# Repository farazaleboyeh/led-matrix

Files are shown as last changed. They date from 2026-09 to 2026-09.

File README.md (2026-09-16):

# Custom-Built Music Display

## Goal
The purpose of this project has been to extend my skills as a hardware engineer, specifically in regards to the development of embedded systems. Thus, I challenged myself to build a complete system from scratch that encompasses the entire development lifecycle. From schematic design and PCB layout in KiCad, to writing efficient C++ firmware for Wi-Fi networking, memory management, & custom LED multiplexing.

## Overview
Repository includes the firmwmare used to show the artwork of a currently streaming song from Spotify onto a custom-built 10x10 display, as well as all primary KiCad project files used to design the system itself. Some examples images of the display in its most recent state are available below.

<div align="center">
  <table>
    <tr>
      <td align="center">
        <a href="assets/demo1.jpeg">
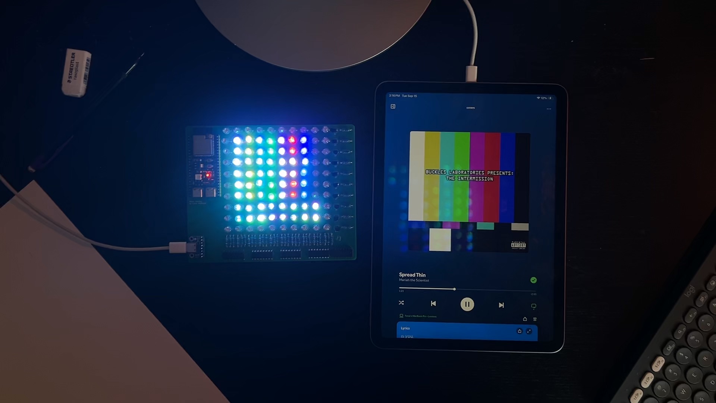
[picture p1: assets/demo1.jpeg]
Example Image 1
          
        </a>
        <br />
        <sub><em>Example 1, raw LEDs exposed.</em></sub>
      </td>
      <td align="center">
        <a href="assets/demo5.jpeg">
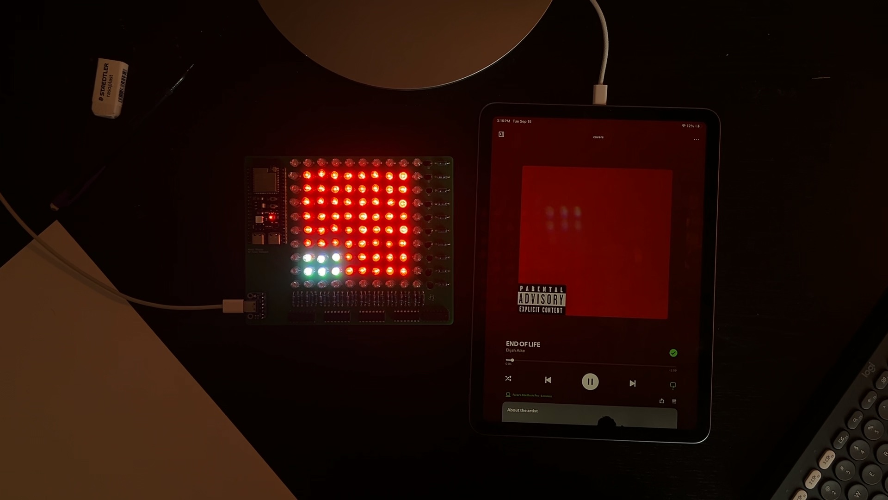
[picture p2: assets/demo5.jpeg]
Example Image 2
          
        </a>
        <br />
        <sub><em>Example 2, raw LEDs exposed.</em></sub>
      </td>
    </tr>
    <tr>
      <td align="center">
        <a href="assets/demo4.jpeg">
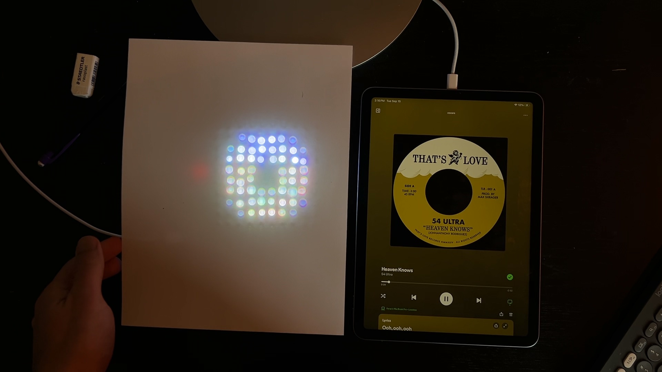
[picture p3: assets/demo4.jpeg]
Example Image 3
          
        </a>
        <br />
        <sub><em>Example 3, makeshift diffuser overlayed. </em></sub>
      </td>
      <td align="center">
      <a href="assets/demo2.jpeg">
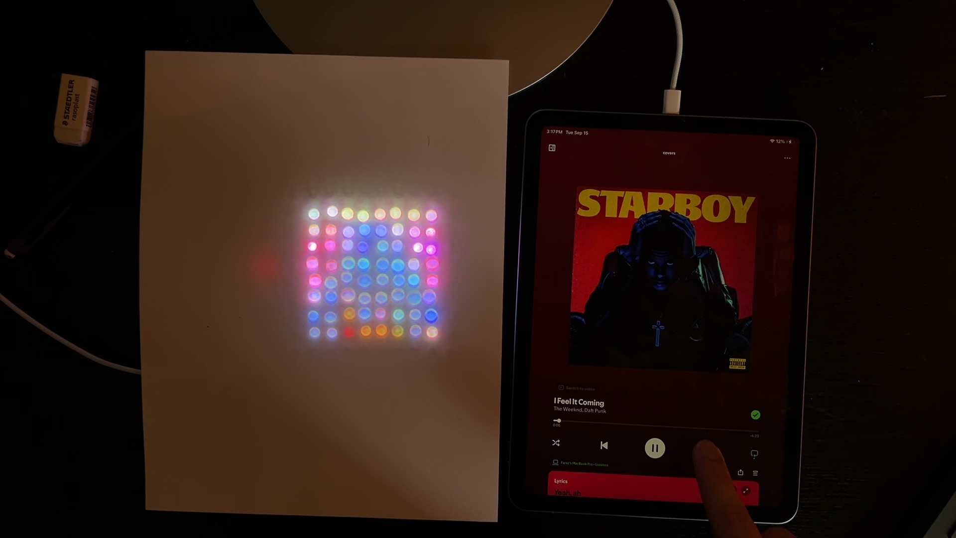
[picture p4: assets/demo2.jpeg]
Example Image 4
          
        </a>
        <br />
        <sub><em>Example 4, makeshift diffuser overlayed.</em></sub>
      </td>
    </tr>
  </table>
</div>

The system works by first calling Spotify's APIs to fetch all data regarding the user's playing music. From the given information, a link to the  album art is then used to store all JPEG data (as a stream of bytes) to an internal buffer. The TJpg Decoder library is used to decode the buffer as RGB565 data (locally), which perpetually reaches out to a separate callback function, which converts again to RGB888 and also writes to the display's back framebuffer. When the front and back framebuffers are swapped, a continuously firing interrupt displays the artwork by streaming the bitplanes (sequentially by time slice and physical row), to the display's shift registers. 

## Hardware 
### Comprehensive Component List
* 100 RGB LEDs, multiplexed
* 10 100Ω, 10 150Ω, 10 220Ω, & 10 1kΩ resistors
* 5 (74HC595) shift registers, daisy-chained.
* 10 PNP BJTs
* An ESP32-S3, development board
* A USB-C breakout board

### Core Physical Functionality
The display is driven by an ESP32 microcontroller, which is responsible for streaming color data to the chained shift registers, among other tasks. Transistors are present along all rows which act as high-side power switches between the main power rail and the shared anodes, so that the (output-limited) shift registers are not solely responsible for driving entire rows themselves. 1kΩ current-limiting resistors are present along rows to protect the shift registers and LEDs from overheating & overcurrent, with per-color resistors along each column to finely tune color output (100Ω for red columns, 150Ω, green, & 220Ω blue). Images of the schematic, PCB design, & soldered board are all shown below for reference.

<div align="center">
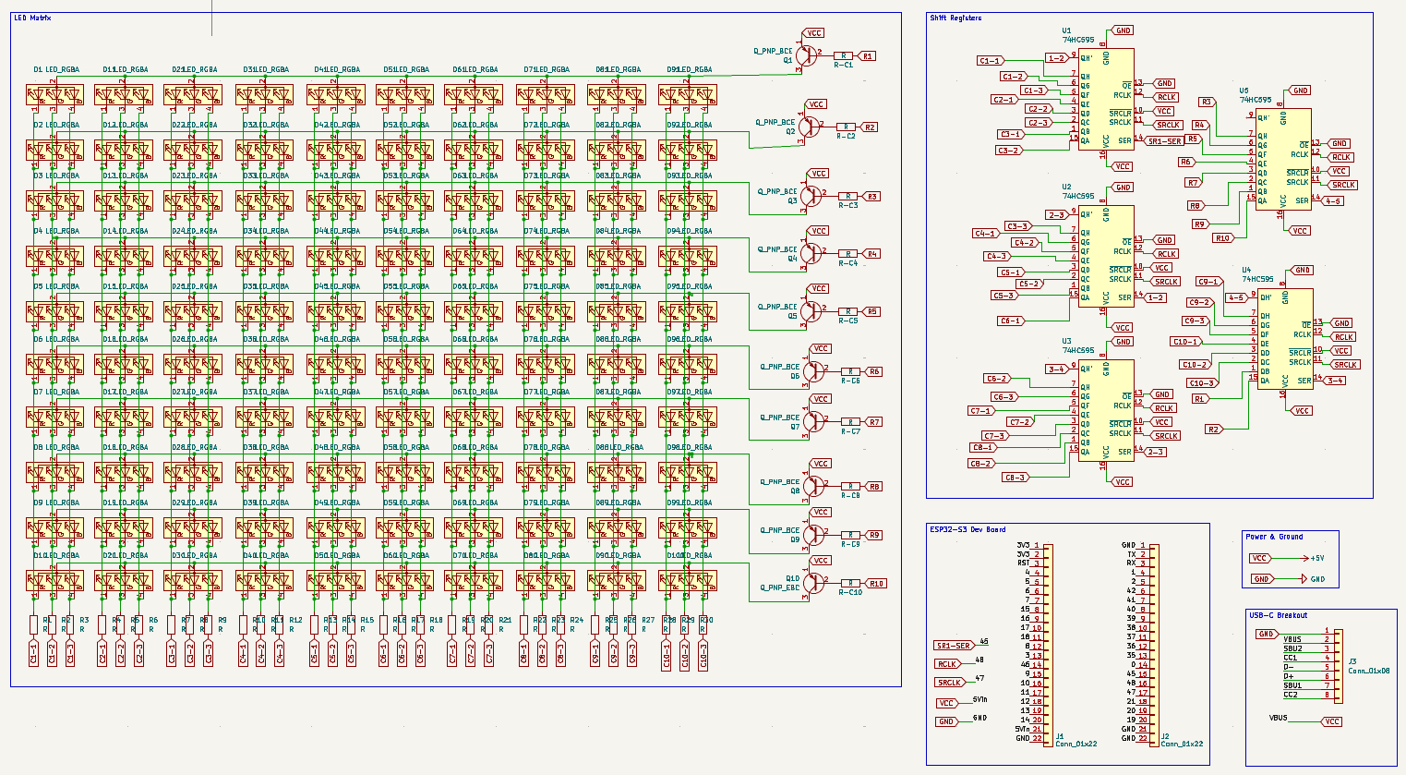
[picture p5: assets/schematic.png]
Image of KiCad Schematic
  
  <br />
  <sub><i>Schematic diagram, designed in KiCad.</i></sub>
</div>

<br />

<div align="center">
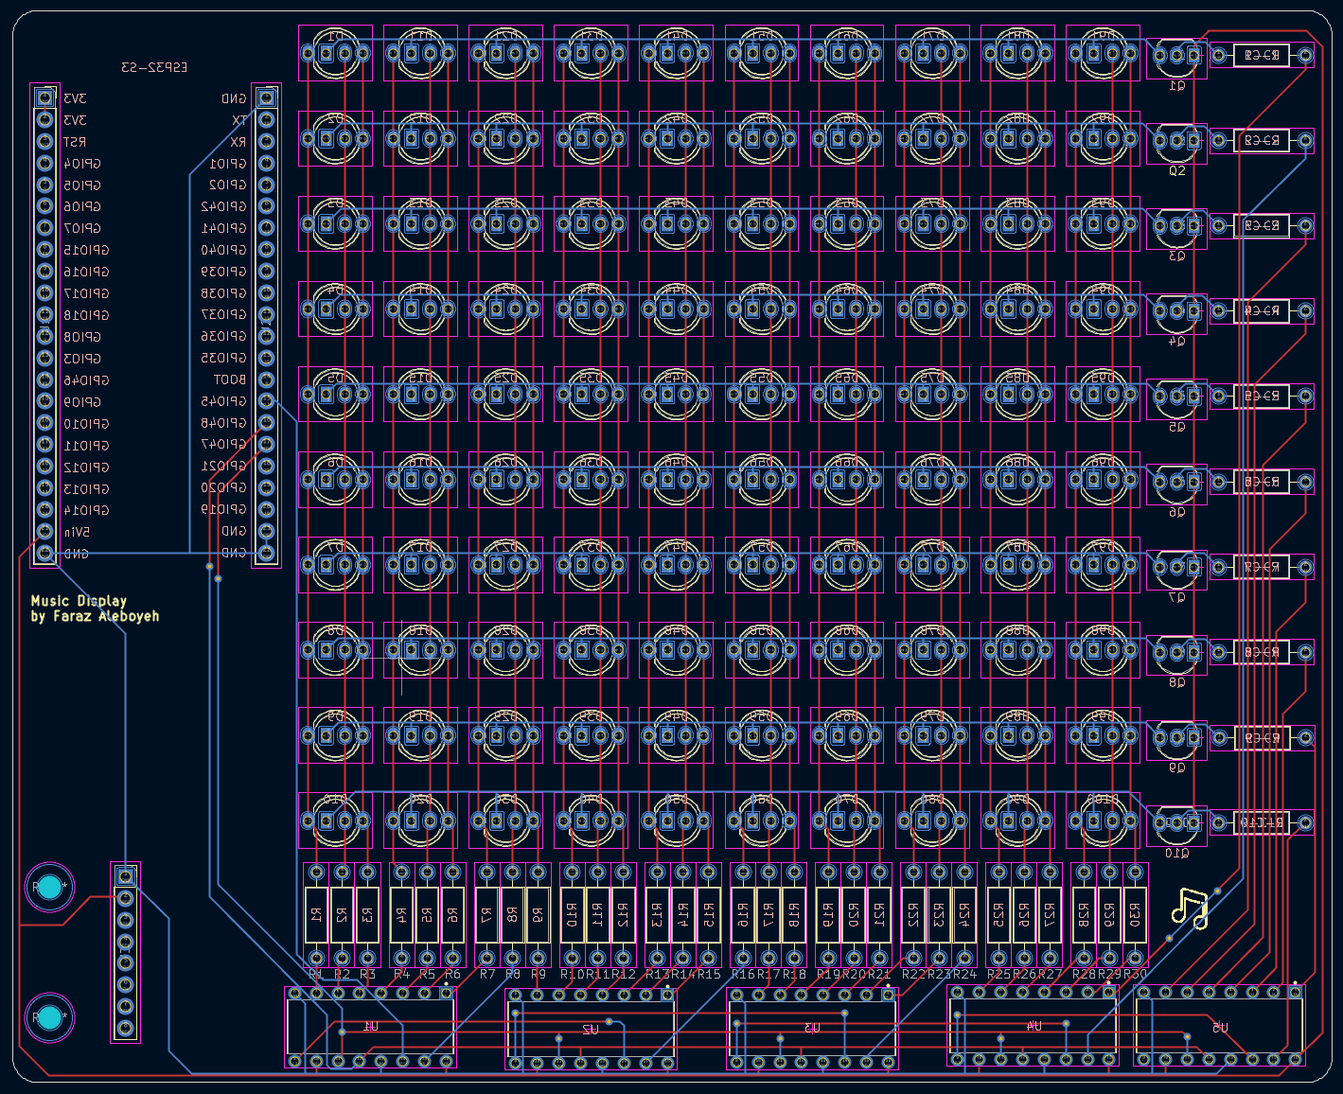
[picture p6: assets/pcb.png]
Image of KiCad PCB Layout
  
  <br />
  <sub><i>PCB layout, designed in KiCad.</i></sub>
</div>

<br />

<div align="center">
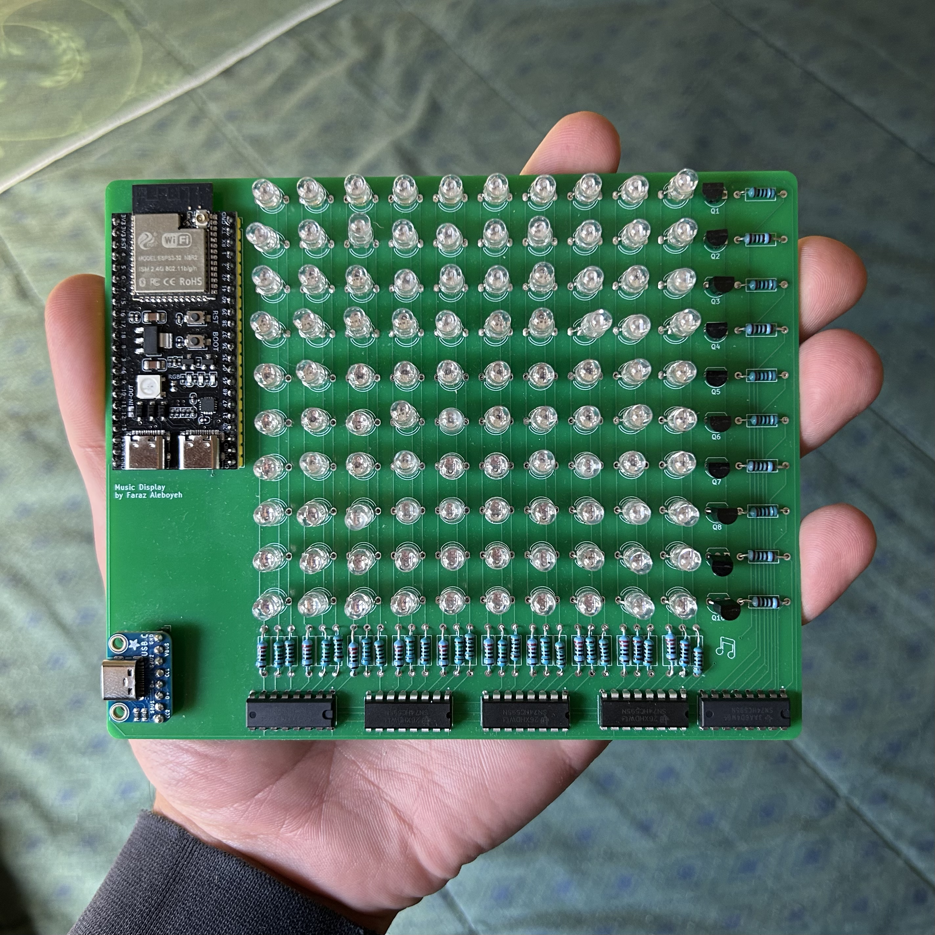
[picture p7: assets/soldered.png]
Image of Soldered PCB
  
  <br />
  <sub><i>Soldered PCB, note that the breakout is still missing the screws and washers necessary for securing it to the board but is otherwise complete.</i></sub>
</div>

## Firmware 
### Core Logical Functionality

<div align="center">
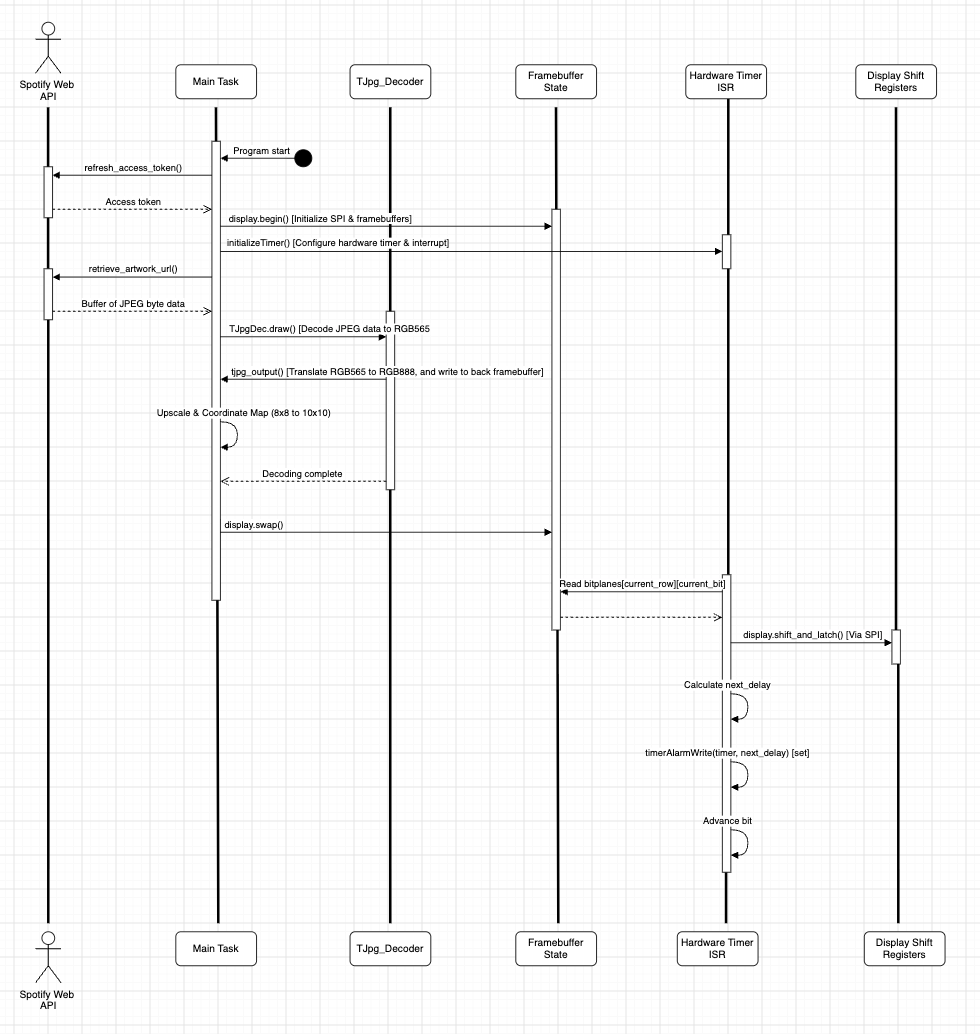
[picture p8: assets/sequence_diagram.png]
Image of UML Sequence Diagram
  
  <br />
  <sub><i>UML sequence diagram, complete program flow.</i></sub>
</div>

### API Access
The basis of the project lies in interfacing with Spotify's APIs to receieve user data regarding their currently playing music. Every time the program begins running, and after a successful Wi-Fi connection is established, one of the first tasks to run is the retrieval of a new Access Token from Spotify's servers. As per the Spotify's requirements, Access Tokens are inherently ephemeral, expiring automatically every 3600 seconds (1 hour) regardless of scope. Thus, a function runs every 55 minutes to renew the Activation Token automatically, ensuring the display can be used for extended periods of time. 

There is not currently, however, any avenue for renewing the Refresh Tokens  automatically at the time of writing. Given they expire every 4 months, an implementation for such was not listed as high-enough priority but is in the works. 

### Interrupt-Driven Binary Code Modulation (BCM)
Instead of standard PWM, which would demand an unsustainable 2,550 SPI updates per frame (10 rows x 255 steps) and cause severe CPU starvation, the driver implements Binary Code Modulation via the microcontroller's hardware timer. By shifting only 8 exponentially weighted bitplanes per row (5µs, 10µs, 20µs, etc.), BCM slashes bus traffic by 97% to just 80 updates per frame, reconstructing full 8-bit color depth through visual persistence while leaving the CPU free for WiFi and JPEG decoding.

### Double Buffering
To prevent screen tearing during WiFi fetches or JPEG decoding: Operations draw to a back framebuffer (`draw_buffer`), `display.swap()` unpacks the back buffer into physical bitplanes (`bitplanes[10][8][5]`), & the ISR (`on_timer`) exclusively reads from the active bitplanes.

## Progress
A list of the main tasks in progress for this project:
* Upscaling the 8x8 artwork to 10x10
* Implementing animated song transitions
* Designing and 3D printing an enlosure and diffuser

A non-exhaustive list of ideas for future iterations of this project:
* LEDs & all other display hardware sitting on separate PCBs
* Playback controls (buttons, or other sensors for touchless playback)
* Transition firmware from Arduino framework to ESP-IDF with FreeRTOS

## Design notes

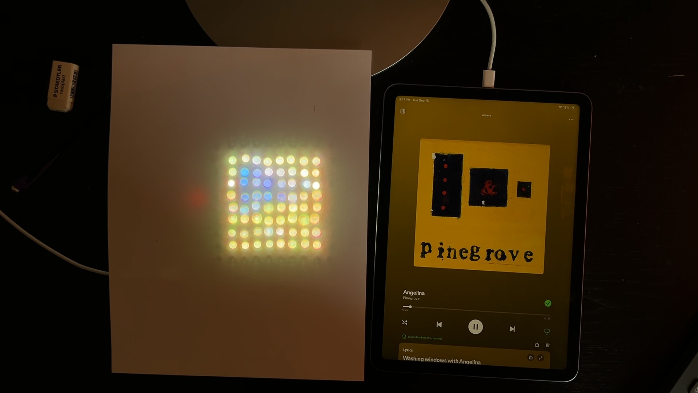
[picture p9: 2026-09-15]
assets/demo3.jpeg

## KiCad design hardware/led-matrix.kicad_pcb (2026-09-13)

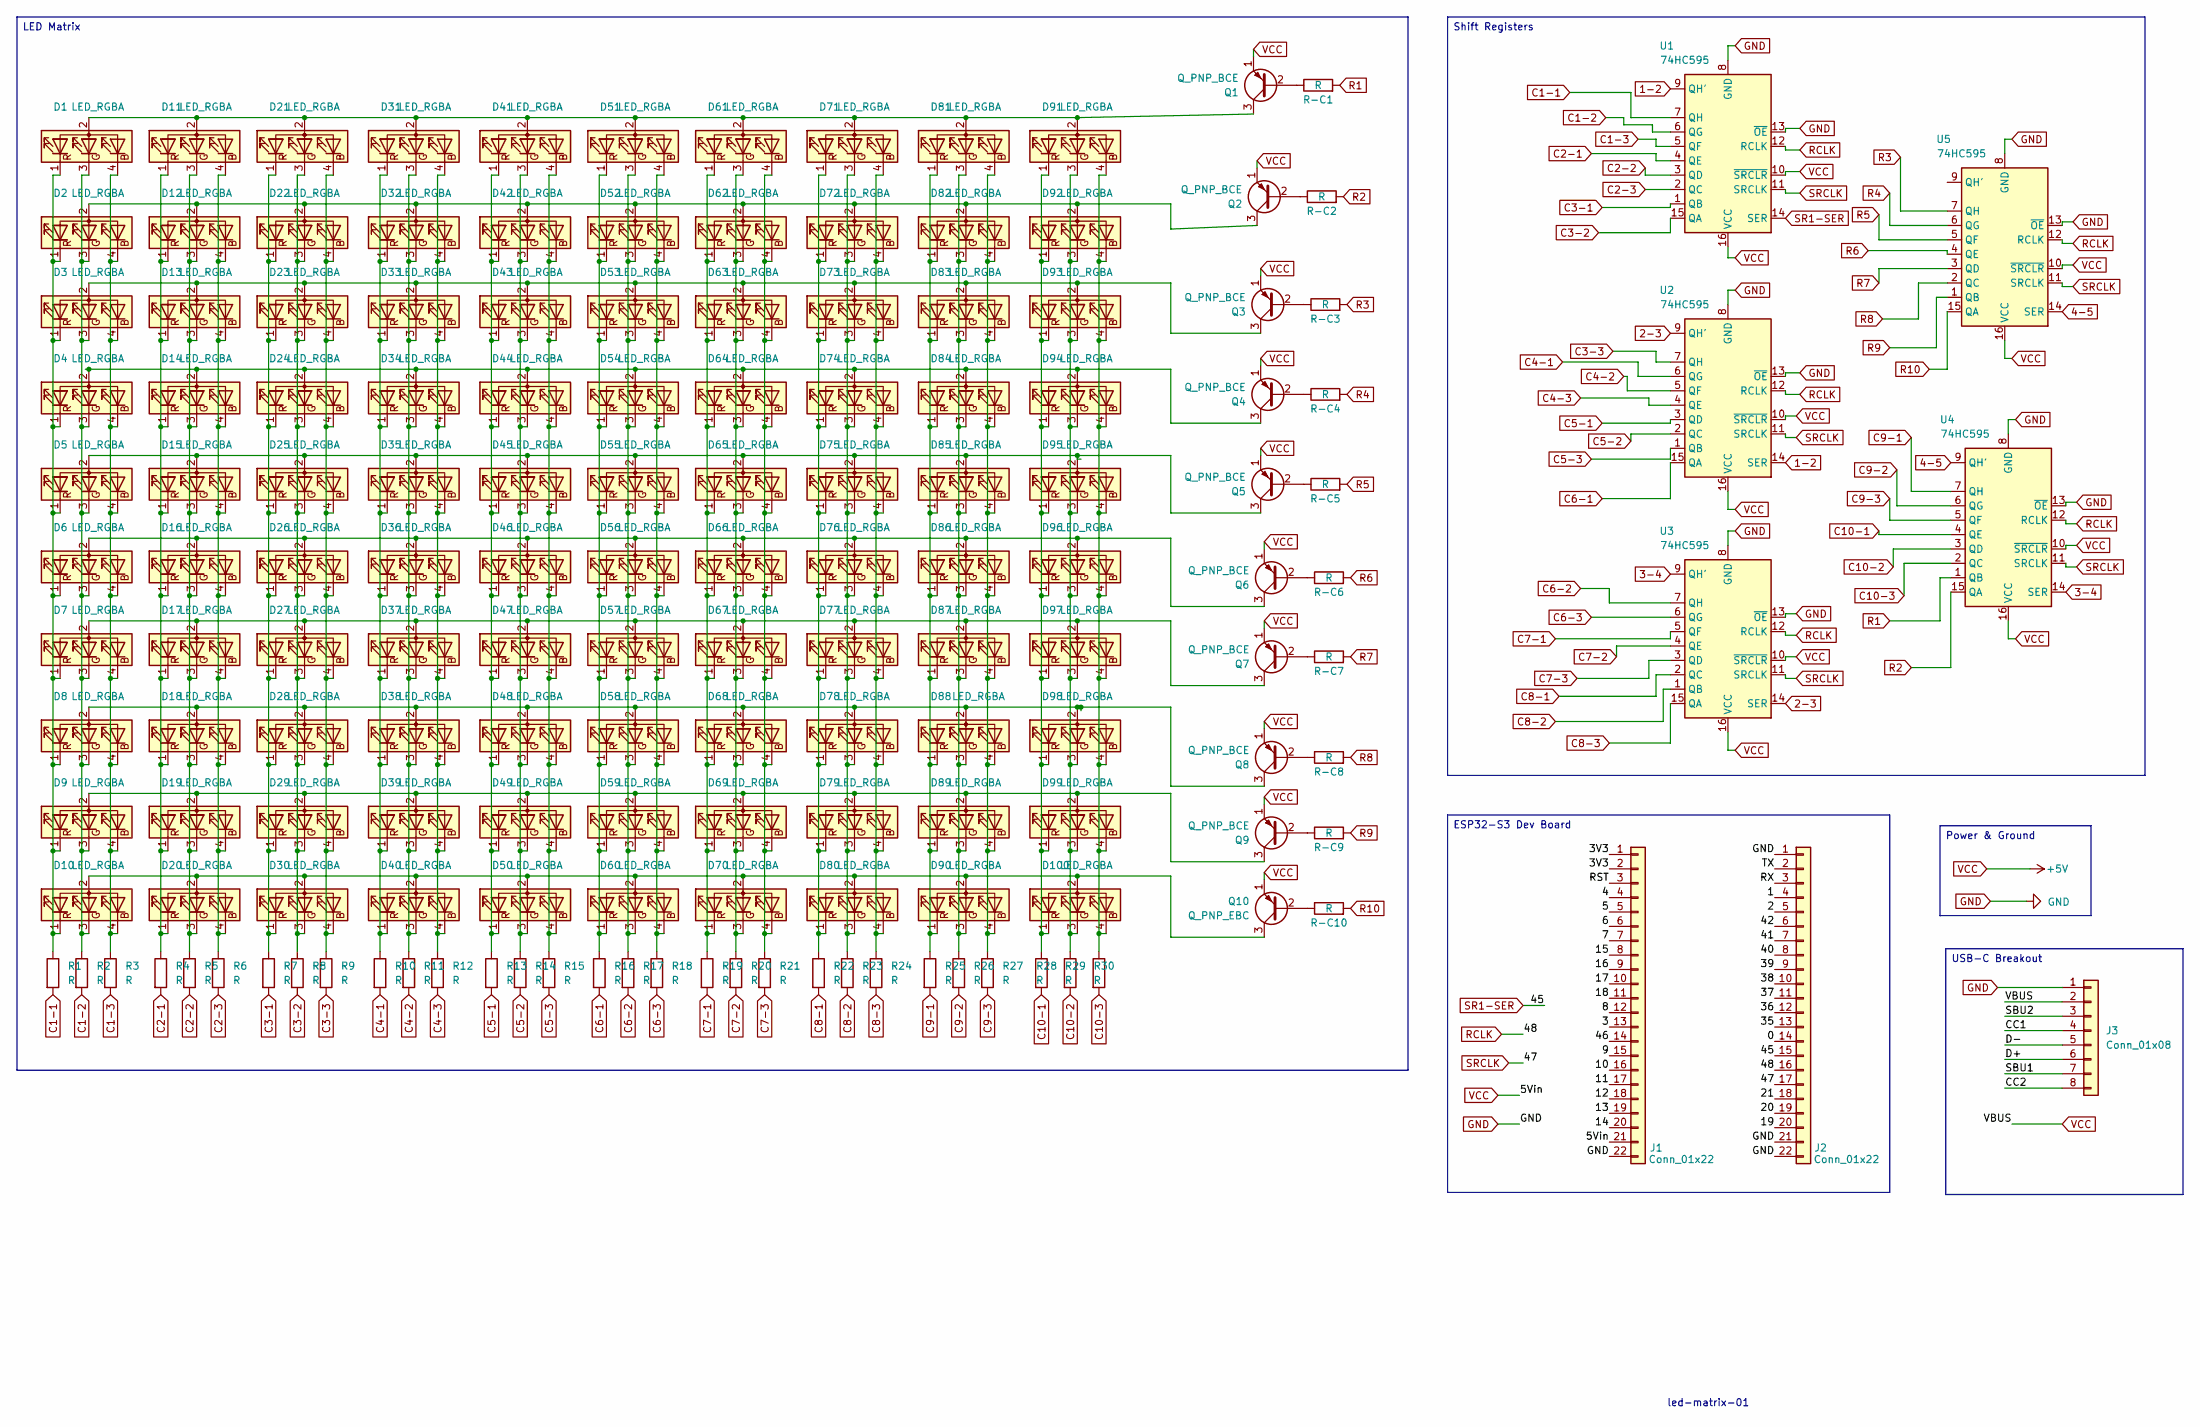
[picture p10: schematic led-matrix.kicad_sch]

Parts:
D1, D2, D3, D4, D5, D6, D7, D8, D9, D10, D11, D12, D13, D14, D15, D16, D17, D18, D19, D20, D21, D22, D23, D24, D25, D26, D27, D28, D29, D30, D31, D32, D33, D34, D35, D36, D37, D38, D39, D40, D41, D42, D43, D44, D45, D46, D47, D48, D49, D50, D51, D52, D53, D54, D55, D56, D57, D58, D59, D60, D61, D62, D63, D64, D65, D66, D67, D68, D69, D70, D71, D72, D73, D74, D75, D76, D77, D78, D79, D80, D81, D82, D83, D84, D85, D86, D87, D88, D89, D90, D91, D92, D93, D94, D95, D96, D97, D98, D99, D100: LED_RGBA; LED_D5.0mm-4_RGB_Wide_Pins
J1, J2: Conn_01x22; PinSocket_1x22_P2.54mm_Vertical
J3: Conn_01x08; PinSocket_1x08_P2.54mm_Vertical
Q1, Q2, Q3, Q4, Q5, Q6, Q7, Q8, Q9: Q_PNP_BCE; TO-92_Inline_Wide
Q10: Q_PNP_EBC; TO-92_Inline_Wide
R1, R2, R3, R4, R5, R6, R7, R8, R9, R10, R11, R12, R13, R14, R15, R16, R17, R18, R19, R20, R21, R22, R23, R24, R25, R26, R27, R28, R29, R30: R; R_Axial_DIN0207_L6.3mm_D2.5mm_P10.16mm_Horizontal
R-C1, R-C2, R-C3, R-C4, R-C5, R-C6, R-C7, R-C8, R-C9, R-C10: R; R_Axial_DIN0207_L6.3mm_D2.5mm_P10.16mm_Horizontal
U1, U2, U3, U4, U5: 74HC595; DIP794W45P254L1969H508Q16

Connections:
1-2: U1.9 (QH'), U2.14 (SER)
2-3: U2.9 (QH'), U3.14 (SER)
3-4: U3.9 (QH'), U4.14 (SER)
4-5: U4.9 (QH'), U5.14 (SER)
/0: J2.14
/1: J2.4
/2: J2.5
/3: J1.13
/3V3: J1.1, J1.2
/4: J1.4
/5: J1.5
/6: J1.6
/7: J1.7
/8: J1.12
/9: J1.15
/10: J1.16
/11: J1.17
/12: J1.18
/13: J1.19
/14: J1.20
/15: J1.8
/16: J1.9
/17: J1.10
/18: J1.11
/19: J2.20
/20: J2.19
/21: J2.18
/35: J2.13
/36: J2.12
/37: J2.11
/38: J2.10
/39: J2.9
/40: J2.8
/41: J2.7
/42: J2.6
/46: J1.14
/CC1: J3.4
/CC2: J3.8
/D+: J3.6
/D-: J3.5
/RST: J1.3
/RX: J2.3
/SBU1: J3.7
/SBU2: J3.3
/TX: J2.2
C1-1: R1.2, U1.7 (QH)
C1-2: R2.2, U1.6 (QG)
C1-3: R3.2, U1.5 (QF)
C2-1: R4.2, U1.4 (QE)
C2-2: R5.2, U1.3 (QD)
C2-3: R6.2, U1.2 (QC)
C3-1: R7.2, U1.1 (QB)
C3-2: R8.2, U1.15 (QA)
C3-3: R9.2, U2.7 (QH)
C4-1: R10.2, U2.6 (QG)
C4-2: R11.2, U2.5 (QF)
C4-3: R12.2, U2.4 (QE)
C5-1: R13.2, U2.3 (QD)
C5-2: R14.2, U2.2 (QC)
C5-3: R15.2, U2.1 (QB)
C6-1: R16.2, U2.15 (QA)
C6-2: R17.2, U3.7 (QH)
C6-3: R18.2, U3.6 (QG)
C7-1: R19.2, U3.5 (QF)
C7-2: R20.2, U3.4 (QE)
C7-3: R21.2, U3.3 (QD)
C8-1: R22.2, U3.2 (QC)
C8-2: R23.2, U3.1 (QB)
C8-3: R24.2, U3.15 (QA)
C9-1: R25.2, U4.7 (QH)
C9-2: R26.2, U4.6 (QG)
C9-3: R27.2, U4.5 (QF)
C10-1: R28.2, U4.4 (QE)
C10-2: R29.2, U4.3 (QD)
C10-3: R30.2, U4.2 (QC)
GND: J1.22, J2.1, J2.21, J2.22, J3.1, U1.8 (GND), U1.13 (~OE), U2.8 (GND), U2.13 (~OE), U3.8 (GND), U3.13 (~OE), U4.8 (GND), U4.13 (~OE), U5.8 (GND), U5.13 (~OE)
unnamed: D1.2 (A), D11.2 (A), D21.2 (A), D31.2 (A), D41.2 (A), D51.2 (A), D61.2 (A), D71.2 (A), D81.2 (A), D91.2 (A), Q1.3 (C)
unnamed: D1.4 (BK), D2.4 (BK), D3.4 (BK), D4.4 (BK), D5.4 (BK), D6.4 (BK), D7.4 (BK), D8.4 (BK), D9.4 (BK), D10.4 (BK), R3.1
unnamed: D1.3 (GK), D2.3 (GK), D3.3 (GK), D4.3 (GK), D5.3 (GK), D6.3 (GK), D7.3 (GK), D8.3 (GK), D9.3 (GK), D10.3 (GK), R2.1
unnamed: D1.1 (RK), D2.1 (RK), D3.1 (RK), D4.1 (RK), D5.1 (RK), D6.1 (RK), D7.1 (RK), D8.1 (RK), D9.1 (RK), D10.1 (RK), R1.1
unnamed: D10.2 (A), D20.2 (A), D30.2 (A), D40.2 (A), D50.2 (A), D60.2 (A), D70.2 (A), D80.2 (A), D90.2 (A), D100.2 (A), Q10.3 (C)
unnamed: D11.4 (BK), D12.4 (BK), D13.4 (BK), D14.4 (BK), D15.4 (BK), D16.4 (BK), D17.4 (BK), D18.4 (BK), D19.4 (BK), D20.4 (BK), R6.1
unnamed: D11.3 (GK), D12.3 (GK), D13.3 (GK), D14.3 (GK), D15.3 (GK), D16.3 (GK), D17.3 (GK), D18.3 (GK), D19.3 (GK), D20.3 (GK), R5.1
unnamed: D11.1 (RK), D12.1 (RK), D13.1 (RK), D14.1 (RK), D15.1 (RK), D16.1 (RK), D17.1 (RK), D18.1 (RK), D19.1 (RK), D20.1 (RK), R4.1
unnamed: D2.2 (A), D12.2 (A), D22.2 (A), D32.2 (A), D42.2 (A), D52.2 (A), D62.2 (A), D72.2 (A), D82.2 (A), D92.2 (A), Q2.3 (C)
unnamed: D3.2 (A), D13.2 (A), D23.2 (A), D33.2 (A), D43.2 (A), D53.2 (A), D63.2 (A), D73.2 (A), D83.2 (A), D93.2 (A), Q3.3 (C)
unnamed: D4.2 (A), D14.2 (A), D24.2 (A), D34.2 (A), D44.2 (A), D54.2 (A), D64.2 (A), D74.2 (A), D84.2 (A), D94.2 (A), Q4.3 (C)
unnamed: D5.2 (A), D15.2 (A), D25.2 (A), D35.2 (A), D45.2 (A), D55.2 (A), D65.2 (A), D75.2 (A), D85.2 (A), D95.2 (A), Q5.3 (C)
unnamed: D6.2 (A), D16.2 (A), D26.2 (A), D36.2 (A), D46.2 (A), D56.2 (A), D66.2 (A), D76.2 (A), D86.2 (A), D96.2 (A), Q6.3 (C)
unnamed: D7.2 (A), D17.2 (A), D27.2 (A), D37.2 (A), D47.2 (A), D57.2 (A), D67.2 (A), D77.2 (A), D87.2 (A), D97.2 (A), Q7.3 (C)
unnamed: D8.2 (A), D18.2 (A), D28.2 (A), D38.2 (A), D48.2 (A), D58.2 (A), D68.2 (A), D78.2 (A), D88.2 (A), D98.2 (A), Q8.3 (C)
unnamed: D9.2 (A), D19.2 (A), D29.2 (A), D39.2 (A), D49.2 (A), D59.2 (A), D69.2 (A), D79.2 (A), D89.2 (A), D99.2 (A), Q9.3 (C)
unnamed: D21.4 (BK), D22.4 (BK), D23.4 (BK), D24.4 (BK), D25.4 (BK), D26.4 (BK), D27.4 (BK), D28.4 (BK), D29.4 (BK), D30.4 (BK), R9.1
unnamed: D21.3 (GK), D22.3 (GK), D23.3 (GK), D24.3 (GK), D25.3 (GK), D26.3 (GK), D27.3 (GK), D28.3 (GK), D29.3 (GK), D30.3 (GK), R8.1
unnamed: D21.1 (RK), D22.1 (RK), D23.1 (RK), D24.1 (RK), D25.1 (RK), D26.1 (RK), D27.1 (RK), D28.1 (RK), D29.1 (RK), D30.1 (RK), R7.1
unnamed: D31.4 (BK), D32.4 (BK), D33.4 (BK), D34.4 (BK), D35.4 (BK), D36.4 (BK), D37.4 (BK), D38.4 (BK), D39.4 (BK), D40.4 (BK), R12.1
unnamed: D31.3 (GK), D32.3 (GK), D33.3 (GK), D34.3 (GK), D35.3 (GK), D36.3 (GK), D37.3 (GK), D38.3 (GK), D39.3 (GK), D40.3 (GK), R11.1
unnamed: D31.1 (RK), D32.1 (RK), D33.1 (RK), D34.1 (RK), D35.1 (RK), D36.1 (RK), D37.1 (RK), D38.1 (RK), D39.1 (RK), D40.1 (RK), R10.1
unnamed: D41.4 (BK), D42.4 (BK), D43.4 (BK), D44.4 (BK), D45.4 (BK), D46.4 (BK), D47.4 (BK), D48.4 (BK), D49.4 (BK), D50.4 (BK), R15.1
unnamed: D41.3 (GK), D42.3 (GK), D43.3 (GK), D44.3 (GK), D45.3 (GK), D46.3 (GK), D47.3 (GK), D48.3 (GK), D49.3 (GK), D50.3 (GK), R14.1
unnamed: D41.1 (RK), D42.1 (RK), D43.1 (RK), D44.1 (RK), D45.1 (RK), D46.1 (RK), D47.1 (RK), D48.1 (RK), D49.1 (RK), D50.1 (RK), R13.1
unnamed: D51.4 (BK), D52.4 (BK), D53.4 (BK), D54.4 (BK), D55.4 (BK), D56.4 (BK), D57.4 (BK), D58.4 (BK), D59.4 (BK), D60.4 (BK), R18.1
unnamed: D51.3 (GK), D52.3 (GK), D53.3 (GK), D54.3 (GK), D55.3 (GK), D56.3 (GK), D57.3 (GK), D58.3 (GK), D59.3 (GK), D60.3 (GK), R17.1
unnamed: D51.1 (RK), D52.1 (RK), D53.1 (RK), D54.1 (RK), D55.1 (RK), D56.1 (RK), D57.1 (RK), D58.1 (RK), D59.1 (RK), D60.1 (RK), R16.1
unnamed: D61.4 (BK), D62.4 (BK), D63.4 (BK), D64.4 (BK), D65.4 (BK), D66.4 (BK), D67.4 (BK), D68.4 (BK), D69.4 (BK), D70.4 (BK), R21.1
unnamed: D61.3 (GK), D62.3 (GK), D63.3 (GK), D64.3 (GK), D65.3 (GK), D66.3 (GK), D67.3 (GK), D68.3 (GK), D69.3 (GK), D70.3 (GK), R20.1
unnamed: D61.1 (RK), D62.1 (RK), D63.1 (RK), D64.1 (RK), D65.1 (RK), D66.1 (RK), D67.1 (RK), D68.1 (RK), D69.1 (RK), D70.1 (RK), R19.1
unnamed: D71.4 (BK), D72.4 (BK), D73.4 (BK), D74.4 (BK), D75.4 (BK), D76.4 (BK), D77.4 (BK), D78.4 (BK), D79.4 (BK), D80.4 (BK), R24.1
unnamed: D71.3 (GK), D72.3 (GK), D73.3 (GK), D74.3 (GK), D75.3 (GK), D76.3 (GK), D77.3 (GK), D78.3 (GK), D79.3 (GK), D80.3 (GK), R23.1
unnamed: D71.1 (RK), D72.1 (RK), D73.1 (RK), D74.1 (RK), D75.1 (RK), D76.1 (RK), D77.1 (RK), D78.1 (RK), D79.1 (RK), D80.1 (RK), R22.1
unnamed: D81.4 (BK), D82.4 (BK), D83.4 (BK), D84.4 (BK), D85.4 (BK), D86.4 (BK), D87.4 (BK), D88.4 (BK), D89.4 (BK), D90.4 (BK), R27.1
unnamed: D81.3 (GK), D82.3 (GK), D83.3 (GK), D84.3 (GK), D85.3 (GK), D86.3 (GK), D87.3 (GK), D88.3 (GK), D89.3 (GK), D90.3 (GK), R26.1
unnamed: D81.1 (RK), D82.1 (RK), D83.1 (RK), D84.1 (RK), D85.1 (RK), D86.1 (RK), D87.1 (RK), D88.1 (RK), D89.1 (RK), D90.1 (RK), R25.1
unnamed: D91.4 (BK), D92.4 (BK), D93.4 (BK), D94.4 (BK), D95.4 (BK), D96.4 (BK), D97.4 (BK), D98.4 (BK), D99.4 (BK), D100.4 (BK), R30.1
unnamed: D91.3 (GK), D92.3 (GK), D93.3 (GK), D94.3 (GK), D95.3 (GK), D96.3 (GK), D97.3 (GK), D98.3 (GK), D99.3 (GK), D100.3 (GK), R29.1
unnamed: D91.1 (RK), D92.1 (RK), D93.1 (RK), D94.1 (RK), D95.1 (RK), D96.1 (RK), D97.1 (RK), D98.1 (RK), D99.1 (RK), D100.1 (RK), R28.1
unnamed: Q1.2 (B), R-C1.1
unnamed: Q2.2 (B), R-C2.1
unnamed: Q3.2 (B), R-C3.1
unnamed: Q4.2 (B), R-C4.1
unnamed: Q5.2 (B), R-C5.1
unnamed: Q6.2 (B), R-C6.1
unnamed: Q7.2 (B), R-C7.1
unnamed: Q8.2 (B), R-C8.1
unnamed: Q9.2 (B), R-C9.1
unnamed: Q10.2 (B), R-C10.1
R1: R-C1.2, U4.1 (QB)
R2: R-C2.2, U4.15 (QA)
R3: R-C3.2, U5.7 (QH)
R4: R-C4.2, U5.6 (QG)
R5: R-C5.2, U5.5 (QF)
R6: R-C6.2, U5.4 (QE)
R7: R-C7.2, U5.3 (QD)
R8: R-C8.2, U5.2 (QC)
R9: R-C9.2, U5.1 (QB)
R10: R-C10.2, U5.15 (QA)
RCLK: J2.16, U1.12 (RCLK), U2.12 (RCLK), U3.12 (RCLK), U4.12 (RCLK), U5.12 (RCLK)
SR1-SER: J2.15, U1.14 (SER)
SRCLK: J2.17, U1.11 (SRCLK), U2.11 (SRCLK), U3.11 (SRCLK), U4.11 (SRCLK), U5.11 (SRCLK)
VCC: J1.21, J3.2, Q1.1 (E), Q2.1 (E), Q3.1 (E), Q4.1 (E), Q5.1 (E), Q6.1 (E), Q7.1 (E), Q8.1 (E), Q9.1 (E), Q10.1 (E), U1.10 (~SRCLR), U1.16 (VCC), U2.10 (~SRCLR), U2.16 (VCC), U3.10 (~SRCLR), U3.16 (VCC), U4.10 (~SRCLR), U4.16 (VCC), U5.10 (~SRCLR), U5.16 (VCC)

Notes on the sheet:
led-matrix-01
USB-C Breakout
Shift Registers
ESP32-S3 Dev Board
LED Matrix
Power & Ground

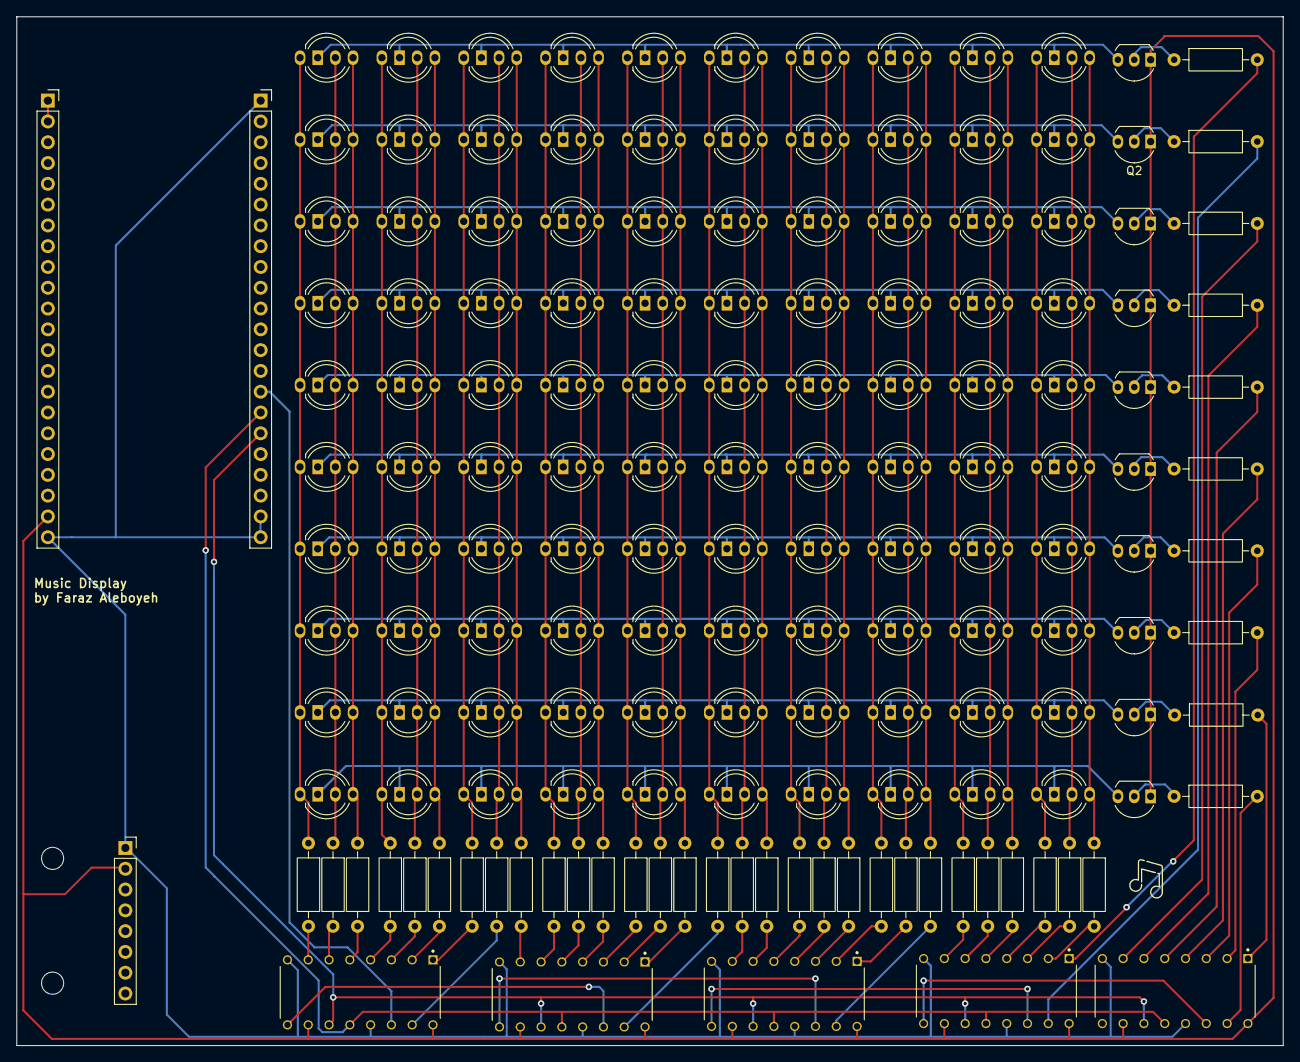
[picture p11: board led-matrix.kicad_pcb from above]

Board: 2 copper layers, 154.7 x 125.7 mm, 158 parts (0 on the bottom side), 100 nets.

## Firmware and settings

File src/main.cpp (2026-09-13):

#include "master.h"

MatrixDriver display;
hw_timer_t *timer = NULL;
WiFiMulti wifiMulti;

volatile int current_row = 0;
volatile int current_bit = 0;

void IRAM_ATTR on_timer()
{
  uint8_t *frame_data = display.bitplanes[current_row][current_bit];
  display.shift_and_latch(frame_data, 5);

  int next_delay = (1 << current_bit) * 5;
  timerAlarmWrite(timer, next_delay, false);
  timerWrite(timer, 0);    
  timerAlarmEnable(timer); 

  current_bit++;
  if (current_bit >= 8)
  {
    current_bit = 0;
    current_row++;
    if (current_row >= 10)
    {
      current_row = 0;
    }
  }
}

bool tjpg_output(int16_t x, int16_t y, uint16_t w, uint16_t h, uint16_t *bitmap)
{
  for (int j = 0; j < h; j++)
  {
    for (int i = 0; i < w; i++)
    {
      int px = x + i + 1;
      int py = y + j + 1;

      if (px < 10 && py < 10 && px >= 0 && py >= 0)
      {
        uint16_t color = bitmap[j * w + i];

        uint8_t r = ((color >> 11) & 0x1F) << 3;
        uint8_t g = ((color >> 5)  & 0x3F) << 2;
        uint8_t b = (color & 0x1F) << 3;

        display.set_pixel(px, py, r, g, b);
      }
    }
  }
  return 1;
}

void setup()
{
  Serial.begin(115200);

  pinMode(latchp, OUTPUT);
  pinMode(clockp, OUTPUT);
  pinMode(datap, OUTPUT);

  wifiMulti.addAP(WIFI_SSID1, WIFI_PASSWORD1);

  while (wifiMulti.run() != WL_CONNECTED)
  {
    delay(100);
  }

  display.begin();

  timer = timerBegin(0, 80, true);
  timerAttachInterrupt(timer, &on_timer, true);
  timerAlarmWrite(timer, 50, false); 
  timerAlarmEnable(timer);

  refresh_access_token();

  TJpgDec.setJpgScale(8);
  TJpgDec.setSwapBytes(false);
  TJpgDec.setCallback(tjpg_output);

  display.clear();
  display.swap();
}

unsigned long last_spotify_check = 0;
const unsigned long SPOTIFY_POLL_INTERVAL = 2000;

void loop()
{
  if (millis() - last_spotify_check >= SPOTIFY_POLL_INTERVAL)
  {
    last_spotify_check = millis();

    if (WiFi.status() == WL_CONNECTED)
    {
      retrieve_artwork_url();
    }
    else
    {
      wifiMulti.run();
    }
  }
}

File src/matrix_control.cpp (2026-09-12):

#include "master.h"

MatrixDriver::MatrixDriver()
{
    draw_buffer = framebuffer_a;
    show_buffer = framebuffer_b;
    clear();
}

void MatrixDriver::begin()
{
    digitalWrite(latchp, LOW);

    // #ifdef oep
    // pinMode(oep, OUTPUT);
    // digitalWrite(oep, HIGH);
    // #endif

    SPI.begin(clockp, -1, datap, -1);

    memset(draw_buffer, 0, NUM_PIXELS * sizeof(RGB));
    memset(show_buffer, 0, NUM_PIXELS * sizeof(RGB));
    memset(bitplanes, 0, sizeof(bitplanes));

    static const uint8_t blank[5] = {0xFF, 0xFF, 0xFF, 0xFF, 0xFF};
    shift_and_latch(blank, 5);

    // #ifdef oep
    //     digitalWrite(oep, LOW); // Enable outputs now that registers are zeroed
    // #endif
}

void MatrixDriver::clear()
{
    memset(draw_buffer, 0, NUM_PIXELS * sizeof(RGB));
}

void MatrixDriver::set_pixel(int x, int y, uint8_t r, uint8_t g, uint8_t b)
{
    if (x < 0 || x >= WIDTH || y < 0 || y >= HEIGHT)
    {
        return;
    }
    int index = (y * WIDTH) + x;
    draw_buffer[index] = {r, g, b};

    // Serial.println(index);
    // Serial.println(std::bitset<8>(r).to_string().c_str());
    // Serial.println(std::bitset<8>(g).to_string().c_str());
    // Serial.println(std::bitset<8>(b).to_string().c_str());
    // Serial.println("---");
}

void MatrixDriver::scan(uint32_t duration_ms)
{
    static const uint8_t blank[5] = {0xFF, 0xFF, 0xFF, 0xFF, 0xFF};

    uint32_t start = millis();
    while (millis() - start < duration_ms)
    {
        for (int y = 0; y < 10; y++)
        {
            for (int bit = 0; bit < 8; bit++)
            {
                shift_and_latch(bitplanes[y][bit], 5);
                int delay_time = (1 << bit) * 5; 
                delayMicroseconds(delay_time);
              
            }
            shift_and_latch(blank, 5);
        }
    }
}

void MatrixDriver::unpack_bitplanes()
{
    for (int y = 0; y < HEIGHT; y++)
    {
        for (int bit = 0; bit < 8; bit++)
        {
            memset(bitplanes[y][bit], 0xFF, 5); // clear all 5 bytes for this row & BCM slice (facilitates bitwise or later)

            for (int x = 0; x < WIDTH; x++)
            {
                int index = (y * WIDTH) + x;
                RGB p = show_buffer[index];
                const PinLocation &loc = COL_MAP[x];

                if (p.r & (1 << bit))
                {
                    bitplanes[y][bit][loc.r.byte_idx] &= ~(1 << loc.r.bit);
                    
                }

                if (p.g & (1 << bit))
                {
                    bitplanes[y][bit][loc.g.byte_idx] &= ~(1 << loc.g.bit);
                }

                if (p.b & (1 << bit))
                {
                    bitplanes[y][bit][loc.b.byte_idx] &= ~(1 << loc.b.bit);
                }
            }
            const RowLocation &rloc = ROW_MAP[y];
            // Serial.println(std::bitset<8>(bitplanes[y][bit][rloc.byte_idx]).to_string().c_str());
            bitplanes[y][bit][rloc.byte_idx] &= ~(1 << rloc.bit);
            // Serial.println(std::bitset<8>(bitplanes[y][bit][rloc.byte_idx]).to_string().c_str());
            // Serial.println("---");
        }
    }
}

void MatrixDriver::swap()
{
    RGB *temp = show_buffer;
    show_buffer = draw_buffer;
    draw_buffer = temp;

    unpack_bitplanes();
}

void MatrixDriver::shift_and_latch(const uint8_t *data, size_t len)
{
    SPI.beginTransaction(SPISettings(10000000, MSBFIRST, SPI_MODE0));
    for (int i = len - 1; i >= 0; i--)
    {
        SPI.transfer(data[i]);
    }

    SPI.endTransaction();

    digitalWrite(latchp, HIGH);
    digitalWrite(latchp, LOW);
}

int MatrixDriver::get_HEIGHT()
{
    return HEIGHT;
}

int MatrixDriver::get_WIDTH()
{
    return WIDTH;
}

// uint16_t MatrixDriver::get_bitplanes(){
//     return bitplanes;
// }

// void set_led(int x, int y, bool state){
//     if (x < 0 || x > 2 || y < 0 || y > 2)
//     {
//         return;
//     }

//     if (!state)
//     {
//         shift_and_latch(0xFFFF);
//         return;
//     }

//     uint16_t row_data = 0b1000000000000000 >> (9 + y);
//     uint16_t col_data = 0b1110000000000000 >> x * 3;

//     uint16_t output = ~(row_data | col_data);
//     shift_and_latch(output);
// }

// void simple_led_cycle()
// {
//     for (int i = 0; i < 3; i++)
//     {
//         for (int j = 0; j < 3; j++)
//         {
//             set_led(i, j, true);
//             delay(500);
//         }
//     }
// }

// void set_row(int y, uint8_t row_pattern)
// {
//     if (y < 0 || y > 2)
//     {
//         return;
//     }

//     uint8_t row_data = 1 << (y + 4);
//     uint16_t col_data = bit_tripler[row_pattern & 0b111];

//     uint16_t output = ~(row_data | col_data);
//     shift_and_latch(output);
// }

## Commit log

2026-08-10 single LED abtraction
2026-08-20 rgb support & framebuffer added
2026-08-20 spring cleaning
2026-08-20 single framebuffer & rgb support complete
2026-09-13 spotify support reintegrated + hardware files added
    [led-matrix.kicad_pcb, led-matrix.kicad_sch]
